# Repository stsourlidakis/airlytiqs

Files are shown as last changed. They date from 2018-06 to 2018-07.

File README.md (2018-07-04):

# AirLytiQs
## Overview
Developed during [#CityChallenge crowdhackathon by Crowdpolicy](http://crowdhackathon.com/smartcity2/en/).
The system measures various environmental parameters and sends them via GPRS to an endpoint, from where data is collected, stored, analyzed and presented in a simple webapp in -mostly- graphical form.

## Screenshots
### Dust
Dust screenshot
### UV
UV screenshot
### CO
CO screenshot

## Tech
### Software
* Database: [PostgreSQL](https://www.postgresql.org/)
* Backend/API: [Node.js](https://nodejs.org/en/), [Express](https://expressjs.com/)
* Frontend: HTML/CSS/JS
* Maps: [OpenLayers](https://openlayers.org/), [OpenStreetMap](https://www.openstreetmap.org/about)

### Hardware
* Arduino Pro 5V/16MHz
* [Optical Dust Sensor - GP2Y1010AU0F](https://www.sparkfun.com/products/9689)
* [Carbon Monoxide Sensor - MQ-7](https://www.sparkfun.com/products/9403)
* [SI1145 UV/Vis/IR](https://learn.adafruit.com/adafruit-si1145-breakout-board-uv-ir-visible-sensor)
* [SIM800 GPRS modem](https://www.ebay.com/itm/SIM800L-GPRS-GSM-Module-Micro-SIM-Card-Board-Quad-band-TTL-Serial-Port-Arduino/323211994162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)
* [LM2596 Step down switcing DC/DC PSU](https://www.ebay.com/itm/2-Pieces-3A-DC-DC-Adjustable-Converter-Step-down-Power-Supply-replace-NI-LM2596S/282226498932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)

License: [MIT](https://tldrlegal.com/license/mit-license)

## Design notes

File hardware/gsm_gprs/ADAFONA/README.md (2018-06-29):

Added support for NeoSWSerial; SoftwareSerial blocks interrupts

Adafruit_FONA_Library
=====================

This is a library for the Adafruit FONA Cellular GSM Breakouts etc

Designed specifically to work with the Adafruit FONA Breakout
  * https://www.adafruit.com/products/1946
  * https://www.adafruit.com/products/1963
  * http://www.adafruit.com/products/2468
  * http://www.adafruit.com/products/2542

These modules use TTL Serial to communicate, 2 pins are required to interface

Adafruit invests time and resources providing this open source code, 
please support Adafruit and open-source hardware by purchasing 
products from Adafruit!

Check out the links above for our tutorials and wiring diagrams 

Written by Limor Fried/Ladyada for Adafruit Industries.  
BSD license, all text above must be included in any redistribution
With updates from Samy Kamkar

To download. click the DOWNLOADS button in the top right corner, rename the uncompressed folder Adafruit_FONA 
Check that the Adafruit_FONA folder contains Adafruit_FONA.cpp and Adafruit_FONA.h

Place the Adafruit_FONA library folder your *arduinosketchfolder*/libraries/ folder. 
You may need to create the libraries subfolder if its your first library. Restart the IDE.

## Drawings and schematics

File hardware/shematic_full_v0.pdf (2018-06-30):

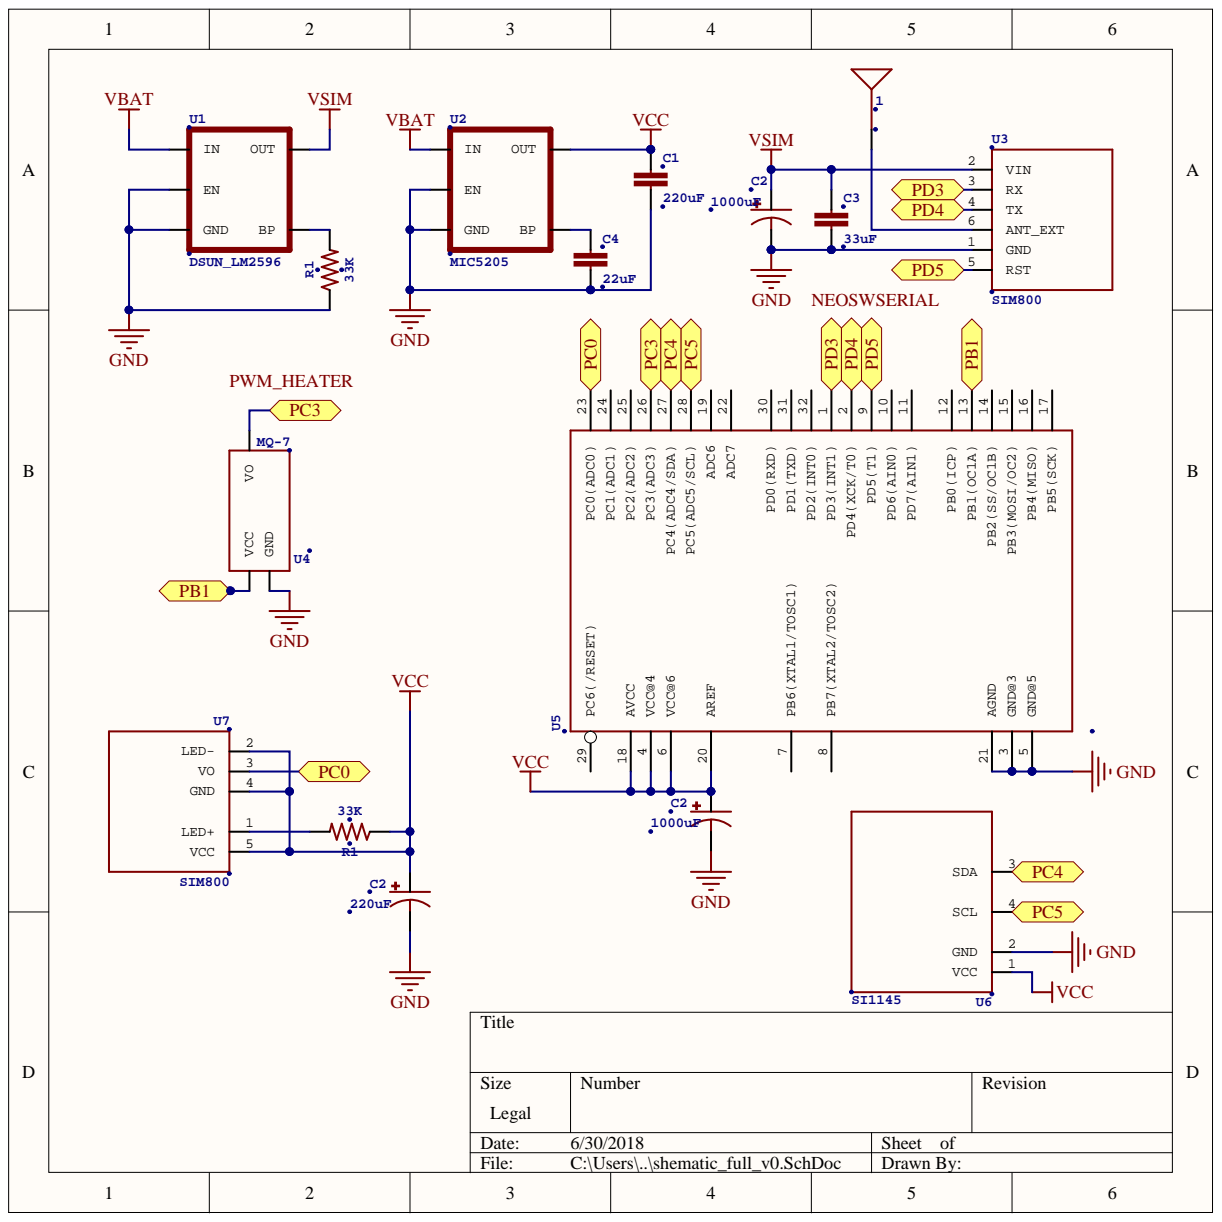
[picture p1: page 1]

PB4(MISO) 16 PB3(MOSI/OC2) 15 PB2(SS/OC1B) 14 PB1(OC1A) 13 PB0(ICP) 12

Size Legal | Number | Revision

Date: 6/30/2018 | Sheet of
File: C:\Users\..\shematic_full_v0.SchDoc | Drawn By:

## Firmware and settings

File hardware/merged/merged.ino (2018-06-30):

#include "gsm_fun.h" // gprs_functions
float Vis, IR, UV, UVindex;

const int samplingTime = 280;     //** follows http://www.howmuchsnow.com/arduino/airquality/
const int sleepTime = 9680;       //**
byte deltaTime      = 40;         //**

float voMeasured =  0;
float calcVoltage = 0;
float dustDensity = 0;


char packet[64] =   {'\0'};
char buffer [25] =  {'\0'};
int CORaw, COppm, dustIndex;

bool hotState, readyToMeas;
unsigned long previousMillis = 0;
long OnTime = 60000;           // milliseconds of on-time
long OffTime = 90000;          // milliseconds of off-time

void setup () {

  Serial.begin(9600);   // Init UART 96008N1
  pinMode(ledPower, OUTPUT);
  pinMode(heater, OUTPUT);
  uv.begin();

  modem.begin(9600);    // init NeoSWSerial 96008N1
  while (!ada_fona.begin(modem)) delay(1000); // give time to provider to register us
  byte notRegistered;                 // counter to handle registration iterations
  while (get_net_stat() != 1)         // netstat = 1 || 5, depends on SIM provider
  {
    delay(250);
    notRegistered++;                  // increase registration iteration count
    if (notRegistered == 127)         // arbitary
    {
      Serial.println(F("get_net_stat() failed"));
      notRegistered = 0;
      break;
    }
  }

  /* staff here is power hungry */
  // ******************************************************************************************************************************************************
  ada_fona.setGPRSNetworkSettings(F("internet"),F(""),F("")); // setup APN
  byte lockCount;                               // counters to handle GPRS lock and POST
  bool passedGPRS = false;
  while (!ada_fona.enableGPRS(true)){           // keep track of gprs lock status
    lockCount++;                                // increase GPRS lock iteration count
    delay(1000);
    if (lockCount == 127)                       // arbitary
    {
      Serial.println(F("GPRS lock failed"));
      lockCount = 0;
      break;
    }
  } passedGPRS = true;
}

void loop() {

  unsigned long currentMillis = millis(); // timekeeping
  /* measure first */
  /* measure UV */
  float Vis = uv.readVisible();
  float IR = uv.readIR();
  float UV = uv.readUV();
  float UVindex = UV / 100.0;
  /* UV ********* */

  /* dust */
  dustDensity = dust_measure(samplingTime, deltaTime, sleepTime);
  if (dustDensity <= 0.5) dustIndex = 0;                          // arb. dust index
  else if (dustDensity > 0.5 && dustDensity <= 15) dustIndex = 1; // arb. dust index  
  else if (dustDensity > 15 && dustDensity <= 400) dustIndex = 3; // arb. dust index
  else dustIndex = 5;
  /* dust */

  /* CO */
  if ((hotState) && (currentMillis - previousMillis >= OnTime)) { /* heat */
    hotState = false;
    readyToMeas = true;
    analogWrite(heater, 80);
    previousMillis = currentMillis;
  }
  else if ((!hotState) && (currentMillis - previousMillis >= OffTime)) { /* cool */
    hotState = true;
    readyToMeas = false;
    digitalWrite(heater, HIGH);
    previousMillis = currentMillis;
  }
  if (readyToMeas) { /* if sensor hot-cold cycled, measure */
    readyToMeas = false;
    CORaw = analogRead(CO);
    COppm = CO_ppm(CORaw);
  }
  /* CO */

  /* then pack */
  itoa (UV, buffer, 10);
  strcpy(packet, buffer);
  strcat(packet, ",");
  buffer[0] = (char)0;

  pack_and_flush(IR, buffer, packet);
  pack_and_flush(Vis, buffer, packet);
  pack_and_flush(UVindex, buffer, packet);
  pack_and_flush(dustDensity, buffer, packet);
  pack_and_flush(dustIndex, buffer, packet);
  pack_and_flush(CORaw, buffer, packet);

  itoa (COppm, buffer, 10);
  strcat(packet, buffer);
  buffer[0] = (char)0;
  /* then pack */

  /* packet ready */
  // for (byte i = 0; i < 64; i++) Serial.print(packet[i]);
  http_post("http://airlytiqs.cloudapp.net/telemetry", packet);
  flush_FONA(); // flash NeoSWSerial
  packet[0] = (char)0;
  // ******************************************************************************************************************************************************
}

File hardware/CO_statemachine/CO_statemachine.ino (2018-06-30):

// state machine for required heating cycles 

#define heater 9
#define CO A3


int CORaw;
int COppm;
bool hotState, readyToMeas;    
unsigned long previousMillis = 0;
long OnTime = 5000;           // milliseconds of on-time
long OffTime = 1000;          // milliseconds of off-time


//Calculate CO PPM
int CO_ppm(double rawValue) {
  double ppm = 3.027 * exp(1.0698 * (rawValue * 5 / 1023));
  return ppm;
}


void setup() 
{
  Serial.begin(9600);   
  pinMode(heater, OUTPUT);      
}

void loop()
{
  unsigned long currentMillis = millis();
  if((hotState) && (currentMillis - previousMillis >= OnTime))
  {
    hotState = false; 
    readyToMeas = true;
    previousMillis = currentMillis;
    analogWrite(heater, 80);
    Serial.println("cold");
  }
  else if ((!hotState) && (currentMillis - previousMillis >= OffTime))
  {
    hotState = true;
    readyToMeas = false;
    Serial.println("hot");

    previousMillis = currentMillis;
    digitalWrite(heater, HIGH);
  }

  if (readyToMeas){
    readyToMeas = false;
    CORaw = analogRead(CO);
    COppm = CO_ppm(CORaw);
    Serial.println("took measurement");
    Serial.print("ADC: ");
    Serial.print(CORaw);
    Serial.print("\t\t ppm: ");
    Serial.print(COppm);
  }


}

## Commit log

2018-06-29 add dust sensor prototype
    10% dynamic memory
2018-06-29 add gprs post prototype, modified ADAFONA for non-blocking interrupt
2018-06-29 create a heatmap with dummy data
2018-06-29 changes SIM800 (D2->D3), free D2 for gas sensor Vcc
2018-06-29 add heatmap maxResolution
2018-06-29 add multiple heatmap layers
2018-06-30 add heatmap randomization on user selections
2018-06-30 implement live heatmap updates 🔥🔥🔥
    adds socket.io
2018-06-30 add pdf/Altium schematics
    [shematic_full_v0.SchDoc]
2018-06-30 implement hourly chart 📈
2018-07-01 add heatmap color legend 🔴🔵
2018-07-01 change default heatmap
